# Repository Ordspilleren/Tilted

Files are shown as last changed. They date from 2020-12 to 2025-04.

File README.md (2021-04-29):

# Tilted

Work in progress hydrometer solution using ESP8266. 

Tilted is very similar to iSpindel, the most popular open-source hydrometer solution, but this project aims to be a simpler, smaller, and more compact version.

The first key difference is in architecture. Instead of connecting the sensor (Tilt) device itself to WiFi, the sensor device instead sends data to a gateway device, which in turns connects to WiFi. This enables two key advantages: First, you can place the gateway close to the sensor itself, which can be advantageous if you have a metal fermentation vessel that hinders the wireless signal. Second, the battery life is greatly improved since the sensor device does not have to worry about anything WiFi related.

Due to the above approach, a conservative estimate of the battery life, assuming most of the uptime is spent in normal mode, would be somewhere around 1 year!

<p align="center">
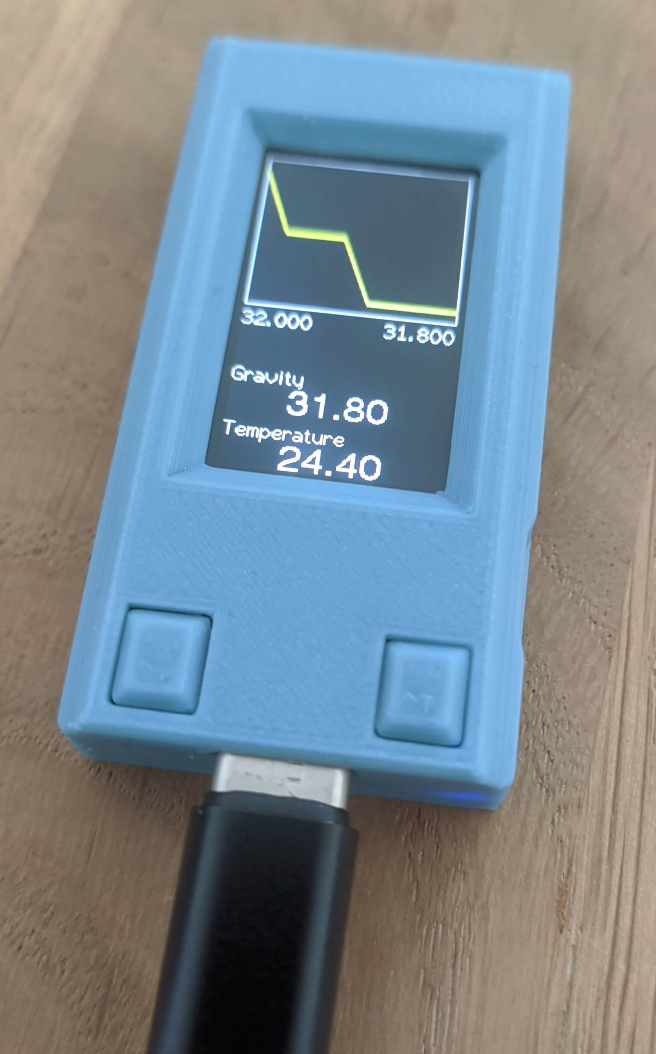
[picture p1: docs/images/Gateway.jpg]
Gateway
  
</p>
<p align="center">
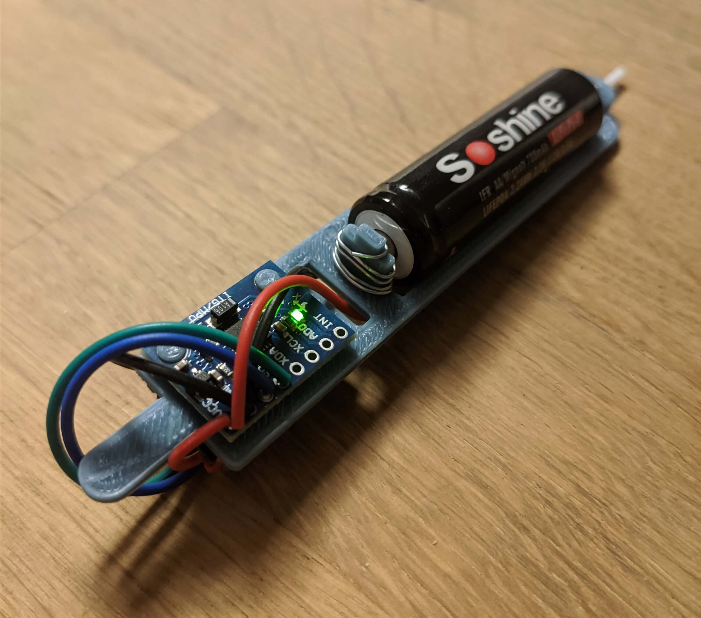
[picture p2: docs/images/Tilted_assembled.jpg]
Tilted assembled
  
</p>
<p align="center">
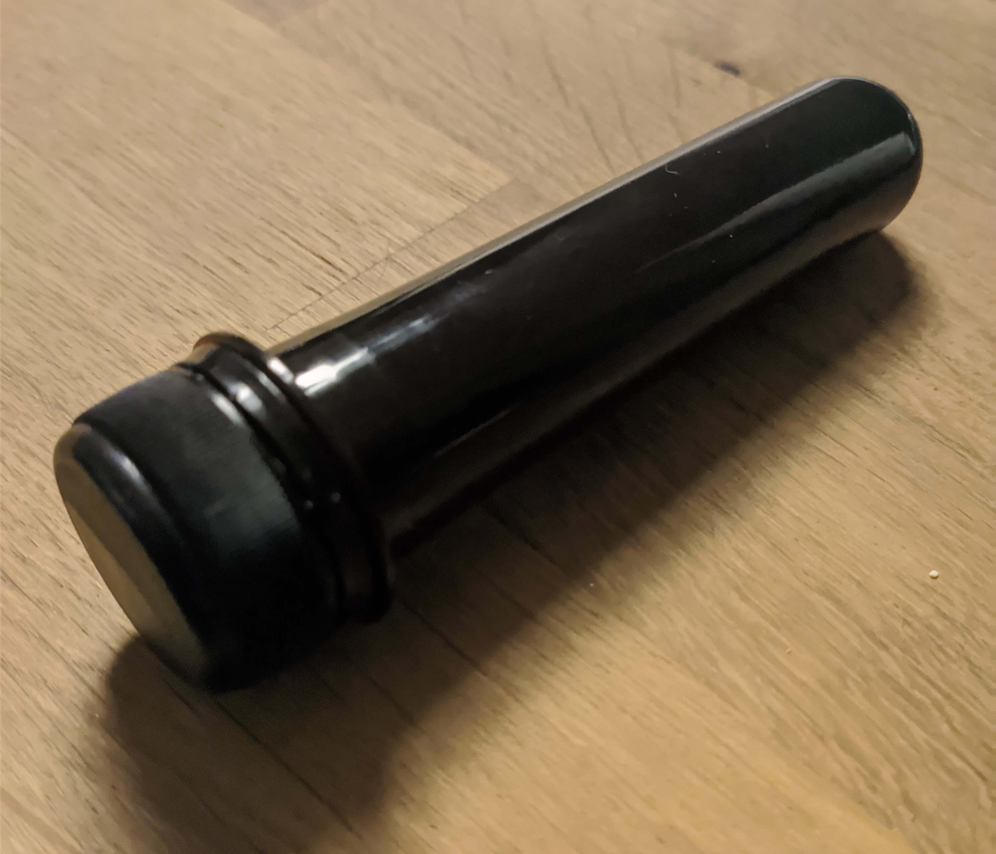
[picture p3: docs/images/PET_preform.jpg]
PET preform
  
</p>

## Features
* **Long battery life**, more than a year!
* **Small footprint.**
* **Flexible positioning** due to the sensor device not connecting directly to WiFi.
  * Great for aluminum fermentation vessels.
* **Several integrations:**
  * Brewfather
  * MQTT
  * InfluxDB
* **Integrations and settings can be updated even when the sensor is in use.**
  * This is possible because integrations are handled by the gateway device.

## Usage
### Calibration mode
Calibration mode can be entered by doing the following:

1. Insert the battery into the sensor device.
2. Within 30 seconds from inserting the battery, place the sensor device with the lid facing down.

This will enable an update interval of 30 seconds for 30 minutes, allowing the user to calibrate the device.

Furthermore, the device will also check for OTA updates. It will do this by trying to connect to the WiFi AP and OTA server defined in the `credentials.h` file.

### 25-degree calibration
Before using the sensor device, you need to calibrate it such that the tilt value is about 25 degrees in plain water. The 3D printed insert includes a handy way to accomplish this:

1. Cut a piece of filament and insert it into the hole at the bottom of the 3D printed insert.
2. Put the sensor into calibration mode.
3. Insert the sensor into the PET preform and put it in plain water. Read the tilt value.
4. If the tilt value is too high, cut off a bit of filament. Measure again.
5. Repeat until the tilt value is 25 ± 3.

## Hardware

Unlike the iSpindel project, Tilted uses a bare ESP-12 module for the sensor device. This has some disadvantages, one of them being that the wiring and initial flashing procedure will be harder since there is no access to USB. The bare module is a hard requirement however since a regular Wemos D1 module is simply too big for the desired footprint. A huge advantage of the bare ESP-12 module is that the battery life of the final product is *greatly* increased.

For the battery, Tilted utilizes the amazing LiFePO4 battery technology. Since LiFePO4 batteries output a nominal voltage of ~3.3V, we can power everything directly from it without using any voltage converters.

### Parts list

For the sensor device itself, the following parts are needed:
* ESP-12F or ESP-12S
  * The S variant might be preferred since it has the required resistors for running built in.
* MPU-6050 Gyro/Accelerometer
* 14500 LiFePO4 battery
  * I personally use Soshine 14500 LiFePO4 batteries, and I highly recommend them.
* 113mm (inner length) x 21mm (inner diameter) PET preform
  * Any type can be used as long as the size is about right. I recommend this: https://www.ebay.com/itm/142622693372.
* 3D printed sled

For the gateway device, you will need these parts:
* TTGO T-Display
  * This is a custom ESP32 board with a TFT display. Can be purchased on Aliexpress.
* 3D printed case

### Wiring the ESP-12

For flashing, the following diagram is sufficient:


For running:

VCC --> EN, MPU VCC, Battery +

GND --> IO15 (pull-down resistor preferred), MPU GND, Battery -

IO16 --> RST

IO4 --> MPU SDA

IO5 --> MPU SCL

## Credits
* [weeSpindel](https://github.com/c-/weeSpindel): I took heavy inspiration from the code, but also the approach as a whole.
* [TTGO T-Display Case](https://www.thingiverse.com/thing:4501444)

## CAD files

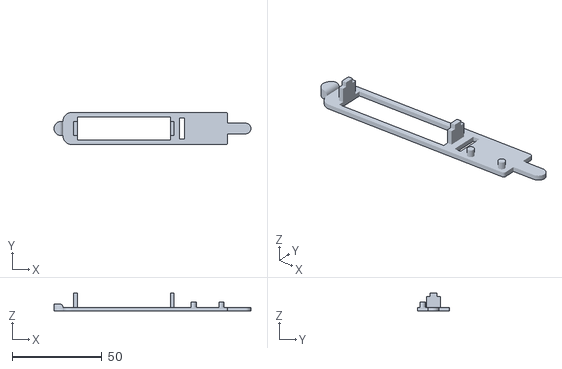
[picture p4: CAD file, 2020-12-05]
3dprint/tilted_insert.stl
110.0 x 18.0 x 10.0

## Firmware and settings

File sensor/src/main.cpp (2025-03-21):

#include <ESP8266WiFi.h>
#include <ESP8266httpUpdate.h>
#include <espnow.h>
#include <Wire.h>
#include "MPU6050.h"
#include "credentials.h"

// Set ADC mode for voltage reading.
ADC_MODE(ADC_VCC);

// Maximum time to be awake, in ms. This is needed in case the MPU sensor
// fails to return any samples.
#define WAKE_TIMEOUT 10000

// I2C pins
#define SDA_PIN 4
#define SCL_PIN 5

// number of tilt samples to average
#define MAX_SAMPLES 5

// Normal interval should be long enough to stretch out battery life. Since
// we're using the MPU temp sensor, we're probably going to see slower
// response times so longer intervals aren't a terrible idea.
#define NORMAL_INTERVAL 1800

// In calibration mode, we need more frequent updates.
// Here we define the RTC address to use and the number of iterations.
// 60 iterations with an interval of 30 equals 30 minutes.
#define CALIBRATION_INTERVAL 30
#define RTC_ADDRESS 0
#define CALIBRATION_ITERATIONS 60
#define CALIBRATION_TILT_ANGLE_MIN 170
#define CALIBRATION_TILT_ANGLE_MAX 180
#define CALIBRATION_SETUP_TIME 30000
#define WIFI_TIMEOUT 10000

// When the battery cell (LiFePO4 in this case) gets this low,
// the ESP switches to every LOW_VOLTAGE_MULTIPLIER*SLEEP_UPDATE_INTERVAL second updates.
#define LOW_VOLTAGE_THRESHOLD 3000
#define LOW_VOLTAGE_MULTIPLIER 4

// Version identifier for OTA.
const char versionTimestamp[] = "TiltedSensor " __DATE__ " " __TIME__;

// Low-pass filter coefficient (0 = no filtering, 1 = ignore new readings)
#define FILTER_ALPHA 0.2

// the following three settings must match the slave settings
uint8_t remoteMac[] = {0x3A, 0x33, 0x33, 0x33, 0x33, 0x33};
const uint8_t channel = 1;
struct __attribute__((packed)) DataStruct
{
	float tilt;
	float temp;
	int volt;
	long interval;
};

DataStruct tiltData;

// when we booted
static unsigned long bootTime, wifiTime, mqttTime, sent, calibrationSetupStart, calibrationWifiStart = 0;

uint32_t calibrationIterations = 0;

// Sensor state variables
enum SensorState {
    STATE_INIT,
    STATE_SAMPLING,
    STATE_PROCESSING,
    STATE_TRANSMITTING,
    STATE_SLEEPING
};

SensorState currentState = STATE_INIT;

RF_PRE_INIT()
{
	bootTime = millis();
}

// Disable RF calibration after deep-sleep wake up.
// This is probably not needed.
//RF_MODE(RF_NO_CAL);

//------------------------------------------------------------
static MPU6050 mpu;
static long sleep_interval = NORMAL_INTERVAL;

//------------------------------------------------------------
static const int led = LED_BUILTIN;

static inline void ledOn()
{
	digitalWrite(led, LOW);
}
static inline void ledOff()
{
	digitalWrite(led, HIGH);
}

//-----------------------------------------------------------------
static void putMpuToSleep()
{
	mpu.setSleepEnabled(true);
    Serial.println("MPU put to sleep");
}

// Calculate tilt angle from accelerometer readings
static float calculateTilt(float ax, float az, float ay)
{
	if (ax == 0 && ay == 0 && az == 0)
		return 0.f;

	return acos(az / (sqrt(ax * ax + ay * ay + az * az))) * 180.0 / PI;
}

// Apply median filter to remove outliers
static float medianFilter(float values[], int size)
{
    // Create a copy of the array for sorting
    float temp[size];
    for (int i = 0; i < size; i++) {
        temp[i] = values[i];
    }
    
    // Simple bubble sort
    for (int i = 0; i < size - 1; i++) {
        for (int j = 0; j < size - i - 1; j++) {
            if (temp[j] > temp[j + 1]) {
                float swap = temp[j];
                temp[j] = temp[j + 1];
                temp[j + 1] = swap;
            }
        }
    }
    
    // Return middle value for odd-sized array
    if (size % 2 == 1) {
        return temp[size / 2];
    } 
    // Return average of two middle values for even-sized array
    else {
        return (temp[size / 2 - 1] + temp[size / 2]) / 2.0;
    }
}

static void actuallySleep()
{
    // Put MPU to sleep if not already done
    putMpuToSleep();
    
    // Turn off WiFi completely to save power
    WiFi.mode(WIFI_OFF);
    WiFi.forceSleepBegin();
    delay(1); // Give WiFi time to shut down

    double uptime = (millis() - bootTime) / 1000.;

    long willsleep = sleep_interval - uptime;
    if (willsleep <= sleep_interval / 2)
    {
        // If we somehow ended up awake longer than half a sleep interval,
        // sleep longer. This shouldn't happen in practice.
        willsleep = sleep_interval;
    }
    Serial.printf("bootTime: %ld WifiTime: %ld mqttTime: %ld\n", bootTime, wifiTime, mqttTime);
    Serial.printf("Deep sleeping %ld seconds after %.3g awake\n", willsleep, uptime);

    ESP.deepSleepInstant(willsleep * 1000000, WAKE_NO_RFCAL);
}

//-----------------------------------------------------------------
static int voltage = 0;

static inline int readVoltage()
{
    // Read voltage multiple times and average for better accuracy
    const int readings = 3;
    int sum = 0;
    for (int i = 0; i < readings; i++) {
        sum += ESP.getVcc();
        delay(5);
    }
    return (voltage = sum / readings);
}

//--------------------------------------------------------------
static unsigned int nsamples = 0;
static float samples[MAX_SAMPLES];
static float temperature = 0.0;

float round1(float value)
{
	return (int)(value * 10 + 0.5) / 10.0;
}

static void sendSensorData()
{
    Serial.println("Processing and sending data...");

    // Apply median filter to samples to remove outliers
    float filteredValue = medianFilter(samples, nsamples);
    
    tiltData.tilt = round1(filteredValue);
    tiltData.temp = round1(temperature);
    tiltData.volt = voltage;
    tiltData.interval = sleep_interval;

    // Initialize WiFi in STA mode
    WiFi.forceSleepWake();
    delay(1);
    WiFi.mode(WIFI_STA);
    WiFi.disconnect();

    unsigned long espnow_start = millis();
    unsigned long timeout = WAKE_TIMEOUT / 2;  // Shorter timeout for ESP-NOW
    
    bool init_success = false;
    while ((millis() - espnow_start) < timeout) {
        if (esp_now_init() == 0) {
            init_success = true;
            break;
        }
        delay(10);
    }
    
    if (!init_success) {
        Serial.println("ESP-NOW init failed, sleeping without sending data");
        actuallySleep();
        return;
    }

    esp_now_set_self_role(ESP_NOW_ROLE_CONTROLLER);
    esp_now_add_peer(remoteMac, ESP_NOW_ROLE_SLAVE, channel, NULL, 0);

    wifiTime = millis();

    uint8_t bs[sizeof(tiltData)];
    memcpy(bs, &tiltData, sizeof(tiltData));

    esp_now_send(NULL, bs, sizeof(tiltData)); // NULL means send to all peers
    sent = millis();
    mqttTime = millis();
    
    Serial.println("Data sent, preparing to sleep");
    
    // Clean up ESP-NOW to save power
    esp_now_deinit();
}

// The only difference between "normal" and "calibration"
// is the update frequency. We still deep sleep between samples.
void calibrationMode(bool firstIteration)
{
	readVoltage();
	sleep_interval = CALIBRATION_INTERVAL;
	if (firstIteration)
	{
		calibrationIterations = 1;
	}
	else
	{
		calibrationIterations += 1;
	}
	ESP.rtcUserMemoryWrite(RTC_ADDRESS, &calibrationIterations, sizeof(calibrationIterations));
}

static bool isCalibrationMode()
{
	return (calibrationIterations != 0) ? true : false;
}

void normalMode()
{
	readVoltage();
	Serial.println(voltage);
	bool lowv = !(voltage != 0 && voltage > LOW_VOLTAGE_THRESHOLD);
	if (lowv)
	{
		Serial.println("Voltage below threshold, sleeping longer");
		sleep_interval *= LOW_VOLTAGE_MULTIPLIER;
	}
}

void wifiConnect()
{
    WiFi.forceSleepWake();
    delay(1);
    WiFi.mode(WIFI_STA);
    WiFi.begin(WIFI_SSID, WIFI_PASS);

    calibrationWifiStart = millis();
    while (WiFi.status() != WL_CONNECTED && (millis() - calibrationWifiStart) < WIFI_TIMEOUT)
    {
        delay(250);
        Serial.print(".");
    }

    Serial.print("\nWiFi connected, IP address: ");
    Serial.println(WiFi.localIP());
}

void checkOTAUpdate()
{
	WiFiClient wifiClient;
	wifiConnect();

	t_httpUpdate_return ret = ESPhttpUpdate.update(wifiClient, OTA_SERVER, OTA_PORT, OTA_PATH, versionTimestamp);
	switch (ret)
	{
	case HTTP_UPDATE_FAILED:
		Serial.println("[OTA] Update failed.");
		break;
	case HTTP_UPDATE_NO_UPDATES:
		Serial.println("[OTA] No update available.");
		break;
	case HTTP_UPDATE_OK:
		Serial.println("[OTA] Update ok."); // may not be called since we reboot the ESP
		break;
	}
}

void setup()
{
	pinMode(led, OUTPUT);
	ledOff();

	Serial.begin(115200);
	Serial.println("Reboot");

	Serial.print("Booting because ");
	Serial.println(ESP.getResetReason());

	Serial.println("Build: " + String(versionTimestamp));

	// Turn off WiFi by default to save power
	WiFi.mode(WIFI_OFF);
	WiFi.forceSleepBegin();

	// INITIALIZE MPU
	Serial.println("Starting MPU-6050");
	Wire.begin(SDA_PIN, SCL_PIN);
	Wire.setClock(400000);

	mpu.initialize();
	mpu.setFullScaleAccelRange(MPU6050_ACCEL_FS_2);
	mpu.setFullScaleGyroRange(MPU6050_GYRO_FS_250);
	mpu.setDLPFMode(MPU6050_DLPF_BW_5);
	mpu.setTempSensorEnabled(true);
	mpu.setInterruptLatch(0); // pulse
	mpu.setInterruptMode(1);  // Active Low
	mpu.setInterruptDrive(1); // Open drain
	mpu.setRate(17);
	mpu.setIntDataReadyEnabled(true);

	// Read RTC memory to get current number of calibration iterations.
	ESP.rtcUserMemoryRead(RTC_ADDRESS, &calibrationIterations, sizeof(calibrationIterations));

	rst_info *resetInfo;
	resetInfo = ESP.getResetInfoPtr();
	if (resetInfo->reason != REASON_DEEP_SLEEP_AWAKE)
	{
		int16_t ax, ay, az;
		float tilt;

		calibrationSetupStart = millis();
		while ((millis() - calibrationSetupStart) < CALIBRATION_SETUP_TIME)
		{
			mpu.getAcceleration(&ax, &az, &ay);
			tilt = calculateTilt(ax, az, ay);
			if (tilt > 0.0 && tilt > CALIBRATION_TILT_ANGLE_MIN && tilt < CALIBRATION_TILT_ANGLE_MAX)
			{
				Serial.println("Checking for OTA update...");
				checkOTAUpdate();

				Serial.println("Initiate calibration mode");
				calibrationMode(true);

				break;
			}
			delay(2000);
		}
	}
	else if (isCalibrationMode() && calibrationIterations < CALIBRATION_ITERATIONS)
	{
		Serial.printf("Calibration mode, %d iterations...", calibrationIterations);
		calibrationMode(false);
	}
	else
	{
		Serial.println("Normal mode");
		normalMode();
	}

	currentState = STATE_SAMPLING;
	Serial.println("Finished setup");
}

void loop()
{
    switch (currentState) {
        case STATE_SAMPLING:
            if (sent) {
                currentState = STATE_SLEEPING;
            }
            else if ((millis() - bootTime) > WAKE_TIMEOUT && !isCalibrationMode()) {
                currentState = STATE_SLEEPING;
            }
            else if (nsamples < MAX_SAMPLES && mpu.getIntDataReadyStatus()) {
                int16_t ax, ay, az;
                mpu.getAcceleration(&ax, &az, &ay);

                float tilt = calculateTilt(ax, az, ay);
                
                // Ignore zero readings as well as readings of precisely 90.
                // Both of these indicate failures to read correct data from the MPU.
                if (tilt > 0.0 && tilt != 90) {
                    samples[nsamples++] = tilt;
                }

                if (nsamples >= MAX_SAMPLES) {
                    // As soon as we have all our samples, read the temperature.
                    // This offset is from the MPU documentation. Displays temperature in degrees C.
                    temperature = mpu.getTemperature() / 340.0 + 36.53;
                    
                    // Put the MPU back to sleep immediately after data collection
                    putMpuToSleep();
                    
                    currentState = STATE_PROCESSING;
                }
            }
            
            // mpu.getIntDataReadyStatus() hits the I2C bus. We don't need
			// to poll every ms while we're gathering samples. Once we have
			// the samples we're just waiting for the transmit to clear, so
			// loop a bit quicker.
            delay((nsamples < MAX_SAMPLES) ? 10 : 1);
            break;
            
        case STATE_PROCESSING:
            // Process data and prepare for transmission
            currentState = STATE_TRANSMITTING;
            break;
            
        case STATE_TRANSMITTING:
            // Send sensor data through ESP-NOW
            sendSensorData();
            currentState = STATE_SLEEPING;
            break;
            
        case STATE_SLEEPING:
            // Go to deep sleep
            actuallySleep();
            break;
            
        default:
            // Should never reach here, but just in case reset to sampling state
            currentState = STATE_SAMPLING;
            break;
    }
}

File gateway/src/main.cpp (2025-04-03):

#include "WiFi.h"
#include <esp_wifi.h>
#include <esp_now.h>
#include <PubSubClient.h>
#include <ArduinoJson.h>
#include <HTTPClient.h>
#include <tinyexpr.h>
#include <Preferences.h>
#include <InfluxDbClient.h>
#include <Button2.h>
#include <TFT_eSPI.h>
#include <SPI.h>
#include <CircularBuffer.h>
#include <WebServer.h>

// Button definitions
#define BUTTON_1 35
#define BUTTON_2 0
Button2 btn1(BUTTON_1);
Button2 btn2(BUTTON_2);

// Init display
TFT_eSPI tft = TFT_eSPI(135, 240);

// Preferences
Preferences preferences;

// Config variables
String deviceName = "TiltedGateway";
String wifiSSID = "";
String wifiPassword = "";
String polynomial = "";
String mqttServer = "";
String mqttTopic = "tilted/data";
String brewfatherURL = "";
String influxdbURL = "";
String influxdbOrg = "";
String influxdbBucket = "";
String influxdbToken = "";
String tiltedURL = "";
String tiltedUsername = "";
String tiltedPassword = "";

// AP mode settings
const char* apSSID = "TiltedGateway-Setup";
const char* apPassword = "tilted123";

// Config mode flag
bool configMode = false;

// Web server
WebServer server(80);

#define RETRY_INTERVAL 5000

// MQTT config
WiFiClient wifiClient;
PubSubClient mqttClient(wifiClient);

// InfluxDB
InfluxDBClient influxClient;
Point influxDataPoint("tilted_data");

// Tilted
WiFiClientSecure secureClient;

// the following three settings must match the slave settings
uint8_t mac[] = {0x3A, 0x33, 0x33, 0x33, 0x33, 0x33};
const uint8_t channel = 1;
struct __attribute__((packed)) DataStruct
{
    float tilt;
    float temp;
    int volt;
    long interval;
};

uint8_t sensorId[6];
DataStruct tiltData;
float tiltGravity = 0;

// Buffer with readings for graph display.
// Can be either tilt value or gravity.
CircularBuffer<float, 24> readingsHistory;

volatile boolean haveReading = false;

// HTML for configuration page
const char CONFIG_HTML[] PROGMEM = R"rawliteral(
    <!DOCTYPE html>
    <html>
    <head>
        <title>Tilted Gateway Configuration</title>
        <meta name="viewport" content="width=device-width, initial-scale=1">
        <style>
            body { font-family: Arial, sans-serif; margin: 0; padding: 20px; }
            .form-group { margin-bottom: 15px; }
            label { display: block; margin-bottom: 5px; }
            input[type="text"], input[type="password"] { width: 100%; padding: 8px; box-sizing: border-box; }
            button { background-color: #4CAF50; color: white; padding: 10px 15px; border: none; cursor: pointer; }
            fieldset { margin-bottom: 20px; }
            .section { margin-bottom: 30px; }
        </style>
    </head>
    <body>
        <h1>Tilted Gateway Configuration</h1>
        <form action="/save" method="post">
            <div class="section">
                <fieldset>
                    <legend>Device Settings</legend>
                    <div class="form-group">
                        <label for="deviceName">Device Name:</label>
                        <input type="text" id="deviceName" name="deviceName" value="%DEVICE_NAME%">
                    </div>
                </fieldset>
            </div>
            
            <div class="section">
                <fieldset>
                    <legend>WiFi Settings</legend>
                    <div class="form-group">
                        <label for="wifiSSID">WiFi SSID:</label>
                        <input type="text" id="wifiSSID" name="wifiSSID" value="%WIFI_SSID%">
                    </div>
                    <div class="form-group">
                        <label for="wifiPassword">WiFi Password:</label>
                        <input type="password" id="wifiPassword" name="wifiPassword" value="%WIFI_PASSWORD%">
                    </div>
                </fieldset>
            </div>
            
            <div class="section">
                <fieldset>
                    <legend>Calibration</legend>
                    <div class="form-group">
                        <label for="polynomial">Polynomial:</label>
                        <input type="text" id="polynomial" name="polynomial" value="%POLYNOMIAL%">
                    </div>
                </fieldset>
            </div>
            
            <div class="section">
                <fieldset>
                    <legend>MQTT Settings</legend>
                    <div class="form-group">
                        <label for="mqttServer">MQTT Server:</label>
                        <input type="text" id="mqttServer" name="mqttServer" value="%MQTT_SERVER%">
                    </div>
                    <div class="form-group">
                        <label for="mqttTopic">MQTT Topic:</label>
                        <input type="text" id="mqttTopic" name="mqttTopic" value="%MQTT_TOPIC%">
                    </div>
                </fieldset>
            </div>
            
            <div class="section">
                <fieldset>
                    <legend>Brewfather Settings</legend>
                    <div class="form-group">
                        <label for="brewfatherURL">Brewfather URL:</label>
                        <input type="text" id="brewfatherURL" name="brewfatherURL" value="%BREWFATHER_URL%">
                    </div>
                </fieldset>
            </div>
            
            <div class="section">
                <fieldset>
                    <legend>InfluxDB Settings</legend>
                    <div class="form-group">
                        <label for="influxdbURL">InfluxDB URL:</label>
                        <input type="text" id="influxdbURL" name="influxdbURL" value="%INFLUXDB_URL%">
                    </div>
                    <div class="form-group">
                        <label for="influxdbOrg">InfluxDB Org:</label>
                        <input type="text" id="influxdbOrg" name="influxdbOrg" value="%INFLUXDB_ORG%">
                    </div>
                    <div class="form-group">
                        <label for="influxdbBucket">InfluxDB Bucket:</label>
                        <input type="text" id="influxdbBucket" name="influxdbBucket" value="%INFLUXDB_BUCKET%">
                    </div>
                    <div class="form-group">
                        <label for="influxdbToken">InfluxDB Token:</label>
                        <input type="text" id="influxdbToken" name="influxdbToken" value="%INFLUXDB_TOKEN%">
                    </div>
                </fieldset>
            </div>
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

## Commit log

2020-11-12 Replaced WiFi and MQTT with ESP-Now
    [main.cpp]
2020-11-26 Added a functional calibration mode
2020-12-05 Add 3D insert STL
    [tilted_insert.stl]
2020-12-06 Fixed config mode and AP always being on
    [main.cpp]
2020-12-13 Add InfluxDB support + gravity calculation fix
    [main.cpp]
2021-04-14 Initial changes for esp32 + display support
2021-04-18 Fix division by zero in tilt calculation
    [main.cpp]
2024-10-23 Fix sensor build with new library version.
    [main.cpp]
2025-03-21 Update sensor reliability and add battery indicator to gateway
